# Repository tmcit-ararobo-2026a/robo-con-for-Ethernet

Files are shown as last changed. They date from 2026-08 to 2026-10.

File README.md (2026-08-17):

# <リポジトリ名>

<!-- 一行でプロジェクトを説明する -->
<プロジェクトの概要を1〜2文で記述>

## 目次

1. [概要](#1-概要)
2. [ドキュメント](#2-ドキュメント)
3. [コントリビューション](#3-コントリビューション)
4. [ビルド・使い方](#4-ビルド使い方)
5. [システム構成](#5-システム構成)
6. [ライセンス](#6-ライセンス)

## 1. 概要

<!-- プロジェクトの目的・背景・解決する課題を記述 -->

## 2. ドキュメント

| ドキュメント | 説明 |
| :-: | :-: |
| [CONTRIBUTING.md](./CONTRIBUTING.md) | 開発フロー・コミット規約・コーディング規約 |
| [docs/coding-rules.md](./docs/coding-rules.md) | コーディング規約の詳細 |
| [docs/uml/](./docs/uml/) | UML図 |

## 3. コントリビューション

[CONTRIBUTING.md](./CONTRIBUTING.md) を参照してください。

## 4. ビルド・使い方

<!-- ビルドのやり方 -->
<!-- 使い方 -->

## 5. システム構成

<!-- ROS2ノード構成・STM32との通信方式・ハードウェア構成 等 -->
<!-- 依存クラスが3つ以上ある場合は docs/uml/ にUML図を作成し、ここにリンクする -->

## 6. ライセンス

本リポジトリは [MITライセンス](./LICENSE) のもとで公開されています。

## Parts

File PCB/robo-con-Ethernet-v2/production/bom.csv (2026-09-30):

Designator | Footprint | Quantity | Value | LCSC Part #
C12, C13, C25, C38, C41, C42, C43, C44, C45, C46, C47, C48, C49, C50, C52, C53, C54, C55, C58, C59, C6 | 0402 | 21 | 0.1uF
C14, C15 | 0402 | 2 | 0.1u
C24, C56, C62, C63 | 0402 | 4 | 4.7uF
C26 | 0402 | 1 | 0.33uF
C28 | 0603 | 1 | 0.1uF
C29 | 0402 | 1 | 2.2uF
C34, C35 | 0402 | 2 | 18pF
C36, C37 | 0402 | 2 | 6.8nF
C39 | 0402 | 1 | 22nF
C40 | 0603 | 1 | 1nF
C51, C57, C60 | 0402 | 3 | 1uF
D1, D17 | 0603 | 2 | R
D10, D13, D5 | 0603 | 3 | B
D11, D12 | 0603 | 2 | W
D14, D15 | 0603 | 2 | O
D16, D3 | 0603 | 2 | G
F1 | 0603 | 1 | box
FB1 | 0603 | 1 | 600Ω/500mA
J1, J3 | JST_ZH_B5B-ZR_1x05_P1.50mm_Vertical | 2 | Conn_01x05
J2 | PinSocket_1x04_P2.54mm_Horizontal | 1 | Conn_01x04
J4 | RJ45_Bel_SI-60062-F | 1 | RJ45_Bel_SI-60062-F
J5 | JST_PH_S2B-PH-K_1x02_P2.00mm_Horizontal | 1 | Conn_01x02
R1, R7 | 0603 | 2 | 1k
R10, R22 | 0603 | 2 | 470
R11, R12, R13, R14, R2, R21, R25, R32, R33, R34, R35, R36, R4, R6, R79, R8, R9 | 0402 | 17 | 1k
R16 | 0402 | 1 | 10
R17, R18, R19, R20 | 0402 | 4 | 49.9k
R23 | 0603 | 1 | 10k
R24 | 0603 | 1 | 4k
R3 | 0402 | 1 | 12.3k
R53 | 0402 | 1 | 1M
R77, R78 | 0402 | 2 | 4.7k
SW1, SW2 | switch_TVAF06-A020B-R | 2 | SW_Push
SW3, SW4 | SKHHLPA010 | 2 | SW_Push
SW5 | 4MS1R202M6QES | 1 | SW_Push_SPDT
SW6, SW7 | 8MS8P1B05VS2QES-C13 | 2 | SW_Push_SPDT
U1 | LQFP-64_10x10mm_P0.5mm | 1 | STM32G474RCTx
U10 | SOT-23-5 | 1 | MCP73831-2-OT
U11, U15 | SOT-363_SC-70-6 | 2 | LM66100DCK
U18 | USB_C_Receptacle_Nelton_5077CR-16-SMC2-BK-TR | 1 | USB_Type-C
U3 | LQFP-48_7x7mm_P0.5mm | 1 | W5500
U5, U7 | RKJXV122400R | 2 | RKJXV122400R
U6 | SOT-89-5 | 1 | NJM2884U1-33
Y2 | XRCGB25M000FFS1AR0 | 1 | XRCGB25M000FFS1AR0

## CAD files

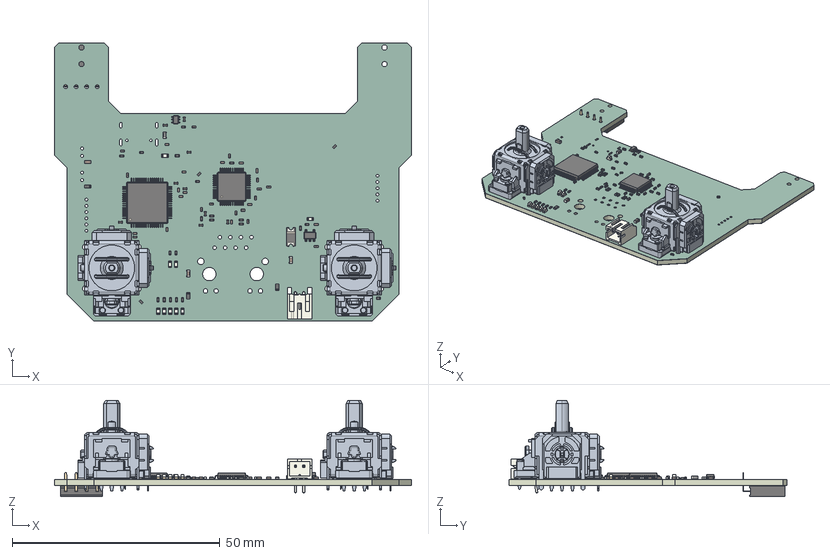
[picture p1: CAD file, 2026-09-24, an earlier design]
PCB/robo-con-Ethernet/.step
86.0 x 67.0 x 23.2 mm
C_0402_1005Metric x 35
R_0402_1005Metric x 26
R_0603_1608Metric x 3
LED_0603_1608Metric x 9
LQFP-64_10x10mm_P0.5mm
.step 1.34 x 2
JST_PH_S2B-PH-K_1x02_P2.00mm_Horizontal
D_2010_5025Metric
C_0603_1608Metric x 3
SOT-23-5
LQFP-48_7x7mm_P0.5mm
SOT-363_SC-70-6
L_0603_1608Metric
PinSocket_1x04_P2.54mm_Horizontal
robo-con-Ethernet_soldermask x 2
robo-con-Ethernet_PCB

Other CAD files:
PCB/robo-con-Ethernet/ほぼ使うやつ.step

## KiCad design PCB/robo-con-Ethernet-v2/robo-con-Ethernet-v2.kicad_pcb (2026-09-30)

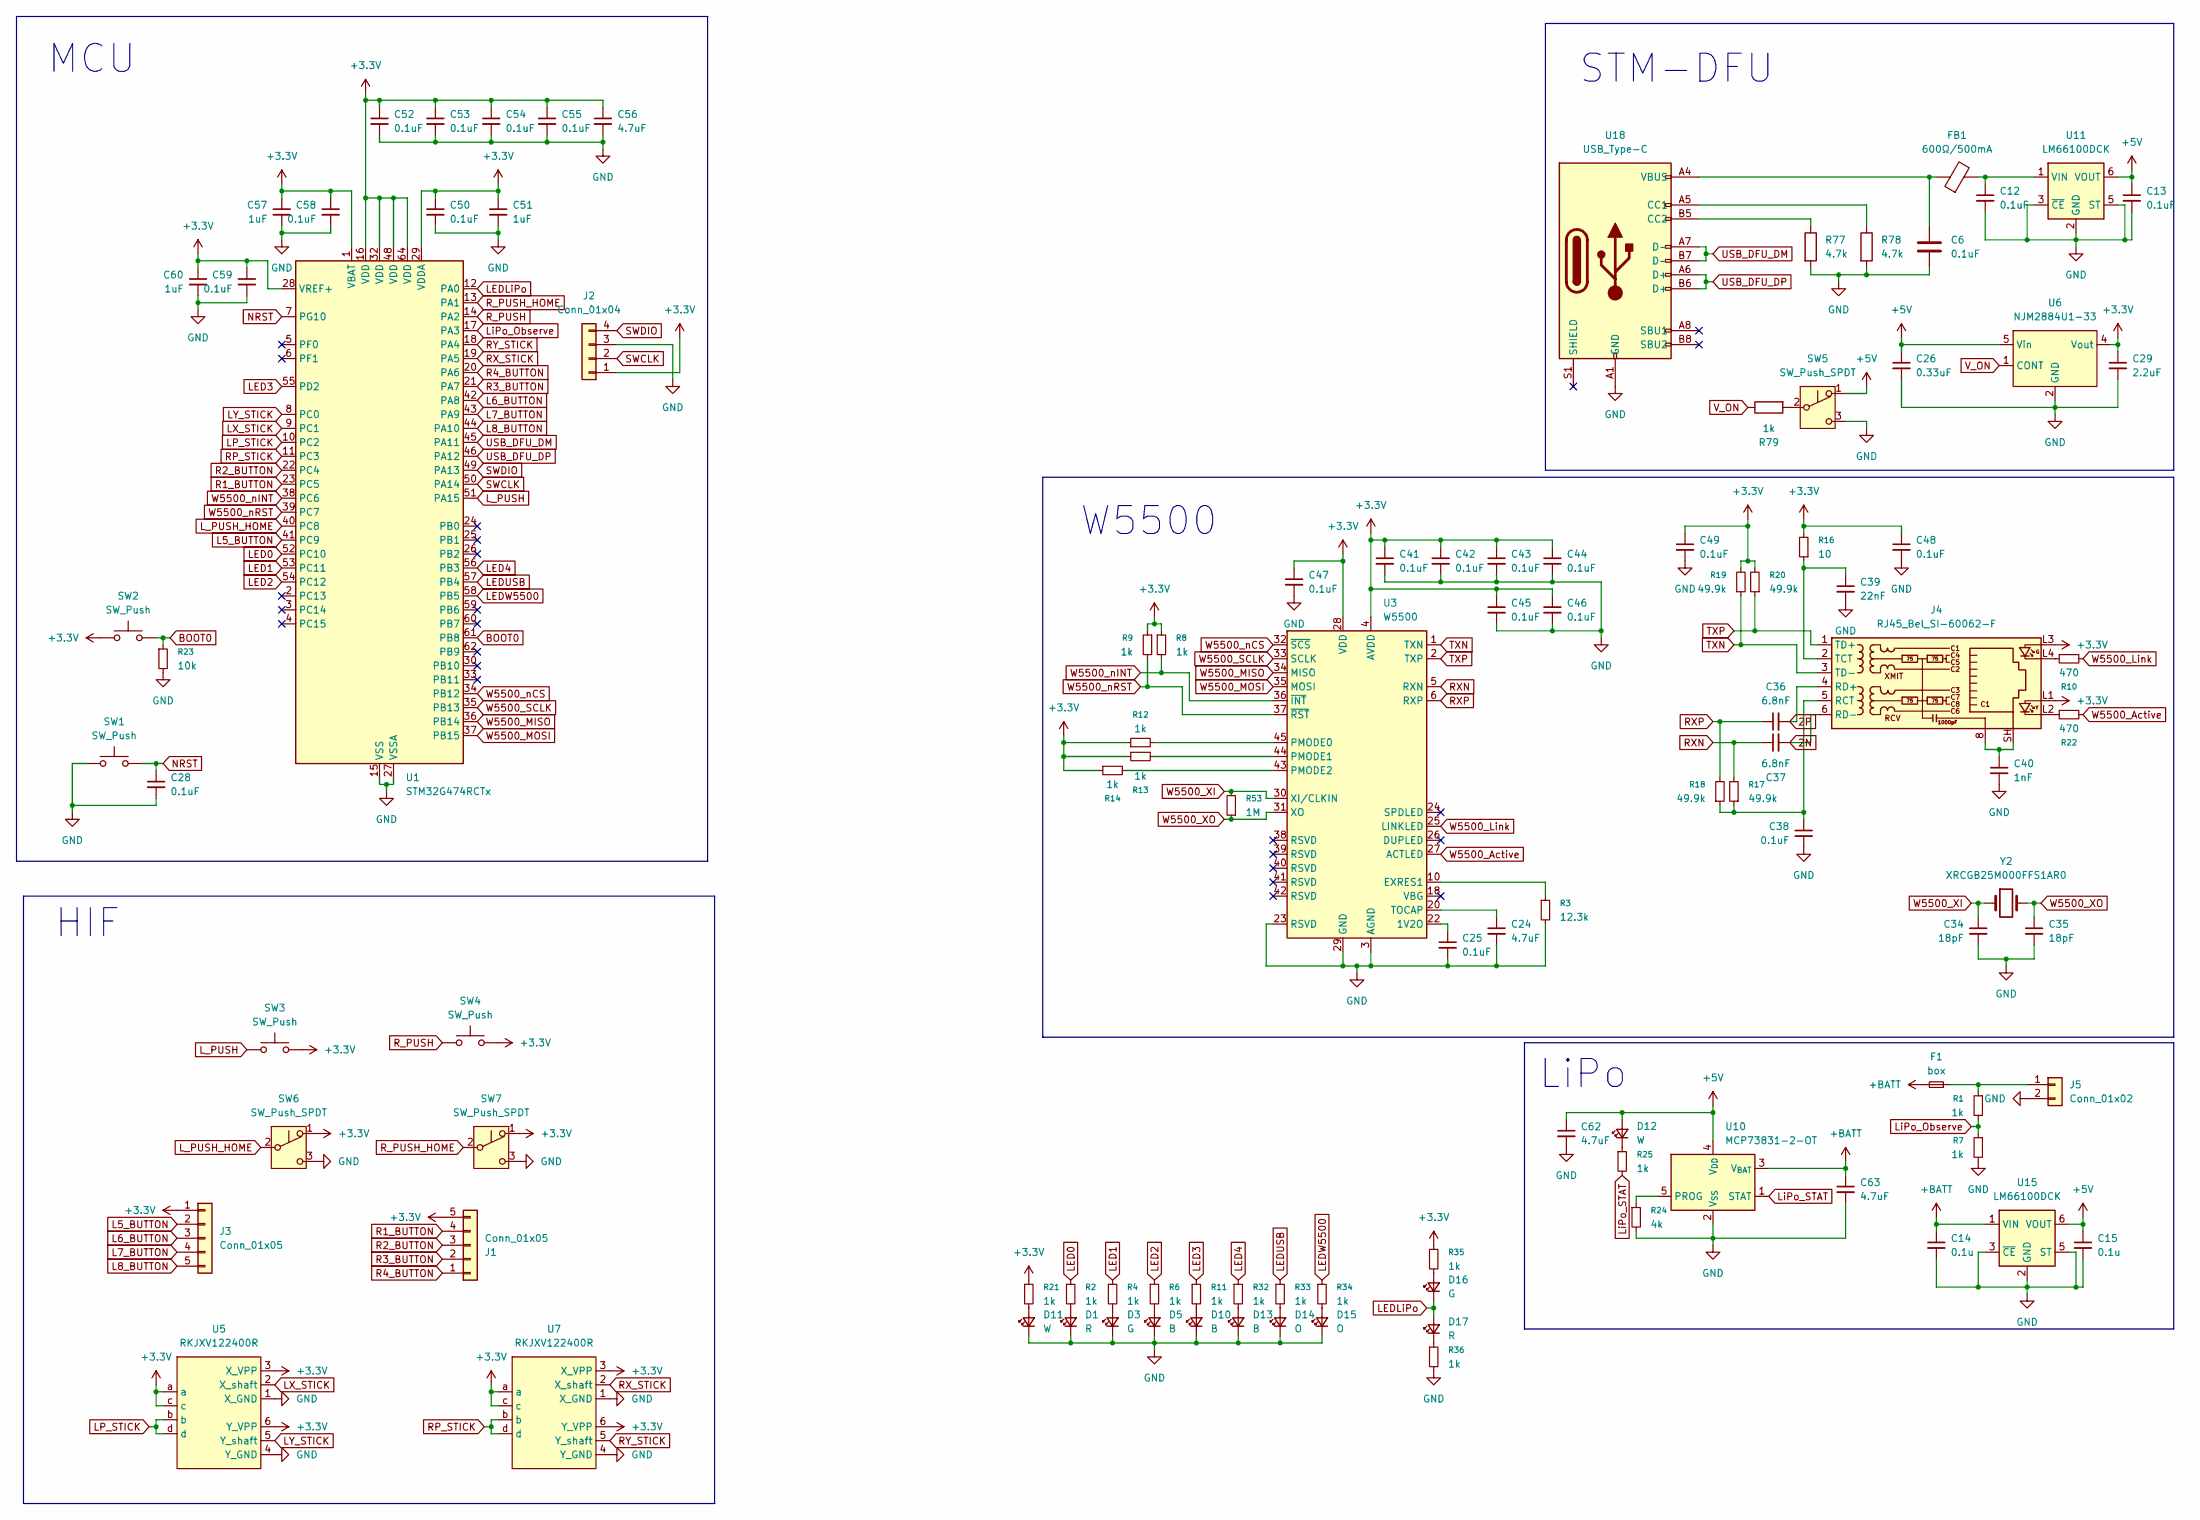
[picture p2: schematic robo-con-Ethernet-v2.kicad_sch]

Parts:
C6, C12, C13, C25, C38, C41, C42, C43, C44, C45, C46, C47, C48, C49, C50, C52, C53, C54, C55, C58, C59: 0.1uF; C_0402_1005Metric_Pad0.74x0.62mm_HandSolder
C14, C15: 0.1u; C_0402_1005Metric_Pad0.74x0.62mm_HandSolder
C24, C56, C62, C63: 4.7uF; C_0402_1005Metric_Pad0.74x0.62mm_HandSolder
C26: 0.33uF; C_0402_1005Metric_Pad0.74x0.62mm_HandSolder
C28: 0.1uF; C_0603_1608Metric_Pad1.08x0.95mm_HandSolder
C29: 2.2uF; C_0402_1005Metric_Pad0.74x0.62mm_HandSolder
C34, C35: 18pF; C_0402_1005Metric_Pad0.74x0.62mm_HandSolder
C36, C37: 6.8nF; C_0402_1005Metric_Pad0.74x0.62mm_HandSolder
C39: 22nF; C_0402_1005Metric_Pad0.74x0.62mm_HandSolder
C40: 1nF; C_0603_1608Metric_Pad1.08x0.95mm_HandSolder
C51, C57, C60: 1uF; C_0402_1005Metric_Pad0.74x0.62mm_HandSolder
D1, D17: R; LED_0603_1608Metric_Pad1.05x0.95mm_HandSolder
D3, D16: G; LED_0603_1608Metric_Pad1.05x0.95mm_HandSolder
D5, D10, D13: B; LED_0603_1608Metric_Pad1.05x0.95mm_HandSolder
D11, D12: W; LED_0603_1608Metric_Pad1.05x0.95mm_HandSolder
D14, D15: O; LED_0603_1608Metric_Pad1.05x0.95mm_HandSolder
F1: box; C_0603_1608Metric_Pad1.08x0.95mm_HandSolder
FB1: 600Ω/500mA; L_0603_1608Metric_Pad1.05x0.95mm_HandSolder
J1, J3: Conn_01x05; JST_ZH_B5B-ZR_1x05_P1.50mm_Vertical
J2: Conn_01x04; PinSocket_1x04_P2.54mm_Horizontal
J4: RJ45_Bel_SI-60062-F
J5: Conn_01x02; JST_PH_S2B-PH-K_1x02_P2.00mm_Horizontal
R1, R7: 1k; R_0603_1608Metric_Pad0.98x0.95mm_HandSolder
R2, R4, R6, R8, R9, R11, R12, R13, R14, R21, R25, R32, R33, R34, R35, R36, R79: 1k; R_0402_1005Metric_Pad0.72x0.64mm_HandSolder
R3: 12.3k; R_0402_1005Metric_Pad0.72x0.64mm_HandSolder
R10, R22: 470; R_0603_1608Metric_Pad0.98x0.95mm_HandSolder
R16: 10; R_0402_1005Metric_Pad0.72x0.64mm_HandSolder
R17, R18, R19, R20: 49.9k; R_0402_1005Metric_Pad0.72x0.64mm_HandSolder
R23: 10k; R_0603_1608Metric_Pad0.98x0.95mm_HandSolder
R24: 4k; R_0603_1608Metric_Pad0.98x0.95mm_HandSolder
R53: 1M; R_0402_1005Metric_Pad0.72x0.64mm_HandSolder
R77, R78: 4.7k; R_0402_1005Metric_Pad0.72x0.64mm_HandSolder
SW1, SW2: SW_Push; switch_TVAF06-A020B-R
SW3, SW4: SW_Push; SKHHLPA010
SW5: SW_Push_SPDT; 4MS1R202M6QES
SW6, SW7: SW_Push_SPDT; 8MS8P1B05VS2QES-C13
U1: STM32G474RCTx; LQFP-64_10x10mm_P0.5mm
U3: W5500; LQFP-48_7x7mm_P0.5mm
U5, U7: RKJXV122400R
U6: NJM2884U1-33; SOT-89-5
U10: MCP73831-2-OT; SOT-23-5
U11, U15: LM66100DCK; SOT-363_SC-70-6
U18: USB_Type-C; USB_C_Receptacle_Nelton_5077CR-16-SMC2-BK-TR
Y2: XRCGB25M000FFS1AR0

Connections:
2N: C37.2, J4.6 (RD-)
2P: C36.2, J4.4 (RD+)
+3.3V: C29.1, C41.1, C42.1, C43.1, C44.1, C45.1, C46.1, C47.1, C48.1, C49.1, C50.1, C51.1, C52.1, C53.1, C54.1, C55.1, C56.1, C57.1, C58.1, C59.1, C60.1, J1.5, J2.1, J3.1, J4.L1, J4.L3, R8.1, R9.1, R12.1, R13.1, R14.1, R16.2, R19.2, R20.2, R21.1, R35.1, SW2.1, SW3.2, SW4.2, SW6.1 (A), SW7.1 (A), U1.1 (VBAT), U1.16 (VDD), U1.28 (VREF+), U1.29 (VDDA), U1.32 (VDD), U1.48 (VDD), U1.64 (VDD), U3.4 (AVDD), U3.8 (AVDD), U3.11 (AVDD), U3.15 (AVDD), U3.17 (AVDD), U3.21 (AVDD), U3.28 (VDD), U5.3 (X_VPP), U5.6 (Y_VPP), U5.a, U5.c, U6.4 (Vout), U7.3 (X_VPP), U7.6 (Y_VPP), U7.a, U7.c
+5V: C13.1, C15.1, C26.1, C62.1, D12.2 (A), SW5.1 (A), U6.5 (Vin), U10.4 (V_{DD}), U11.6 (VOUT), U15.6 (VOUT)
+BATT: C14.1, C63.1, F1.2, U10.3 (V_{BAT}), U15.1 (VIN)
BOOT0: R23.1, SW2.2, U1.61 (PB8)
GND: C6.2, C12.2, C13.2, C14.2, C15.2, C24.2, C25.2, C26.2, C28.2, C29.2, C34.2, C35.2, C38.2, C39.2, C40.2, C41.2, C42.2, C43.2, C44.2, C45.2, C46.2, C47.2, C48.2, C49.2, C50.2, C51.2, C52.2, C53.2, C54.2, C55.2, C56.2, C57.2, C58.2, C59.2, C60.2, C62.2, C63.2, D1.1 (K), D3.1 (K), D5.1 (K), D10.1 (K), D11.1 (K), D13.1 (K), D14.1 (K), D15.1 (K), J2.3, J5.2, R3.2, R7.2, R23.2, R24.2, R36.2, R77.2, R78.2, SW1.1, SW5.3 (C), SW6.3 (C), SW7.3 (C), U1.15 (VSS), U1.27 (VSSA), U1.31 (VSS), U1.47 (VSS), U1.63 (VSS), U3.3 (AGND), U3.9 (AGND), U3.14 (AGND), U3.16 (AGND), U3.19 (AGND), U3.23 (RSVD), U3.29 (GND), U3.48 (AGND), U5.1 (X_GND), U5.4 (Y_GND), U6.2 (GND), U7.1 (X_GND), U7.4 (Y_GND), U10.2 (V_{SS}), U11.2 (GND), U11.3 (~CE), U11.5 (ST), U15.2 (GND), U15.3 (~CE), U15.5 (ST), U18.A1 (GND), U18.B1 (GND)
L5_BUTTON: J3.2, U1.41 (PC9)
L6_BUTTON: J3.3, U1.42 (PA8)
L7_BUTTON: J3.4, U1.43 (PA9)
L8_BUTTON: J3.5, U1.44 (PA10)
LED0: R2.1, U1.52 (PC10)
LED1: R4.1, U1.53 (PC11)
LED2: R6.1, U1.54 (PC12)
LED3: R11.1, U1.55 (PD2)
LED4: R32.1, U1.56 (PB3)
LEDLiPo: D16.1 (K), D17.2 (A), U1.12 (PA0)
LEDUSB: R33.1, U1.57 (PB4)
LEDW5500: R34.1, U1.58 (PB5)
LP_STICK: U1.10 (PC2), U5.b, U5.d
LX_STICK: U1.9 (PC1), U5.2 (X_shaft)
LY_STICK: U1.8 (PC0), U5.5 (Y_shaft)
L_PUSH: SW3.1, U1.51 (PA15)
L_PUSH_HOME: SW6.2 (B), U1.40 (PC8)
LiPo_Observe: R1.2, R7.1, U1.17 (PA3)
LiPo_STAT: R25.2, U10.1 (STAT)
NRST: C28.1, SW1.2, U1.7 (PG10)
unnamed: C6.1, FB1.1, U18.A4 (VBUS), U18.B4 (VBUS)
unnamed: C40.1, J4.8, J4.SH
unnamed: D1.2 (A), R2.2
unnamed: D3.2 (A), R4.2
unnamed: D5.2 (A), R6.2
unnamed: D10.2 (A), R11.2
unnamed: D11.2 (A), R21.2
unnamed: D12.1 (K), R25.1
unnamed: D13.2 (A), R32.2
unnamed: D14.2 (A), R33.2
unnamed: D15.2 (A), R34.2
unnamed: D16.2 (A), R35.2
unnamed: D17.1 (K), R36.1
unnamed: J4.L2, R22.1
unnamed: J4.L4, R10.1
unnamed: C38.1, J4.5 (RCT), R17.1, R18.1
unnamed: C39.1, J4.2 (TCT), R16.1
unnamed: F1.1, J5.1, R1.1
unnamed: R79.2, SW5.2 (B)
unnamed: C25.1, U3.22 (1V2O)
unnamed: R3.1, U3.10 (EXRES1)
unnamed: R12.2, U3.45 (PMODE0)
unnamed: R13.2, U3.44 (PMODE1)
unnamed: R14.2, U3.43 (PMODE2)
unnamed: C24.1, U3.20 (TOCAP)
unnamed: R24.1, U10.5 (PROG)
unnamed: C12.1, FB1.2, U11.1 (VIN)
unnamed: R78.1, U18.A5 (CC1)
unnamed: R77.1, U18.B5 (CC2)
R1_BUTTON: J1.4, U1.23 (PC5)
R2_BUTTON: J1.3, U1.22 (PC4)
R3_BUTTON: J1.2, U1.21 (PA7)
R4_BUTTON: J1.1, U1.20 (PA6)
RP_STICK: U1.11 (PC3), U7.b, U7.d
RXN: C37.1, R17.2, U3.5 (RXN)
RXP: C36.1, R18.2, U3.6 (RXP)
RX_STICK: U1.19 (PA5), U7.2 (X_shaft)
RY_STICK: U1.18 (PA4), U7.5 (Y_shaft)
R_PUSH: SW4.1, U1.14 (PA2)
R_PUSH_HOME: SW7.2 (B), U1.13 (PA1)
SWCLK: J2.2, U1.50 (PA14)
SWDIO: J2.4, U1.49 (PA13)
TXN: J4.3 (TD-), R19.1, U3.1 (TXN)
TXP: J4.1 (TD+), R20.1, U3.2 (TXP)
USB_DFU_DM: U1.45 (PA11), U18.A7 (D-), U18.B7 (D-)
USB_DFU_DP: U1.46 (PA12), U18.A6 (D+), U18.B6 (D+)
V_ON: R79.1, U6.1 (CONT)
W5500_Active: R22.2, U3.27 (ACTLED)
W5500_Link: R10.2, U3.25 (LINKLED)
W5500_MISO: U1.36 (PB14), U3.34 (MISO)
W5500_MOSI: U1.37 (PB15), U3.35 (MOSI)
W5500_SCLK: U1.35 (PB13), U3.33 (SCLK)
W5500_XI: C34.1, R53.2, U3.30 (XI/CLKIN), Y2.1
W5500_XO: C35.1, R53.1, U3.31 (XO), Y2.3 (2)
W5500_nCS: U1.34 (PB12), U3.32 (~SCS)
W5500_nINT: R8.2, U1.38 (PC6), U3.36 (~INT)
W5500_nRST: R9.2, U1.39 (PC7), U3.37 (~RST)

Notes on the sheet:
LiPo
W5500
STM-DFU
MCU
HIF

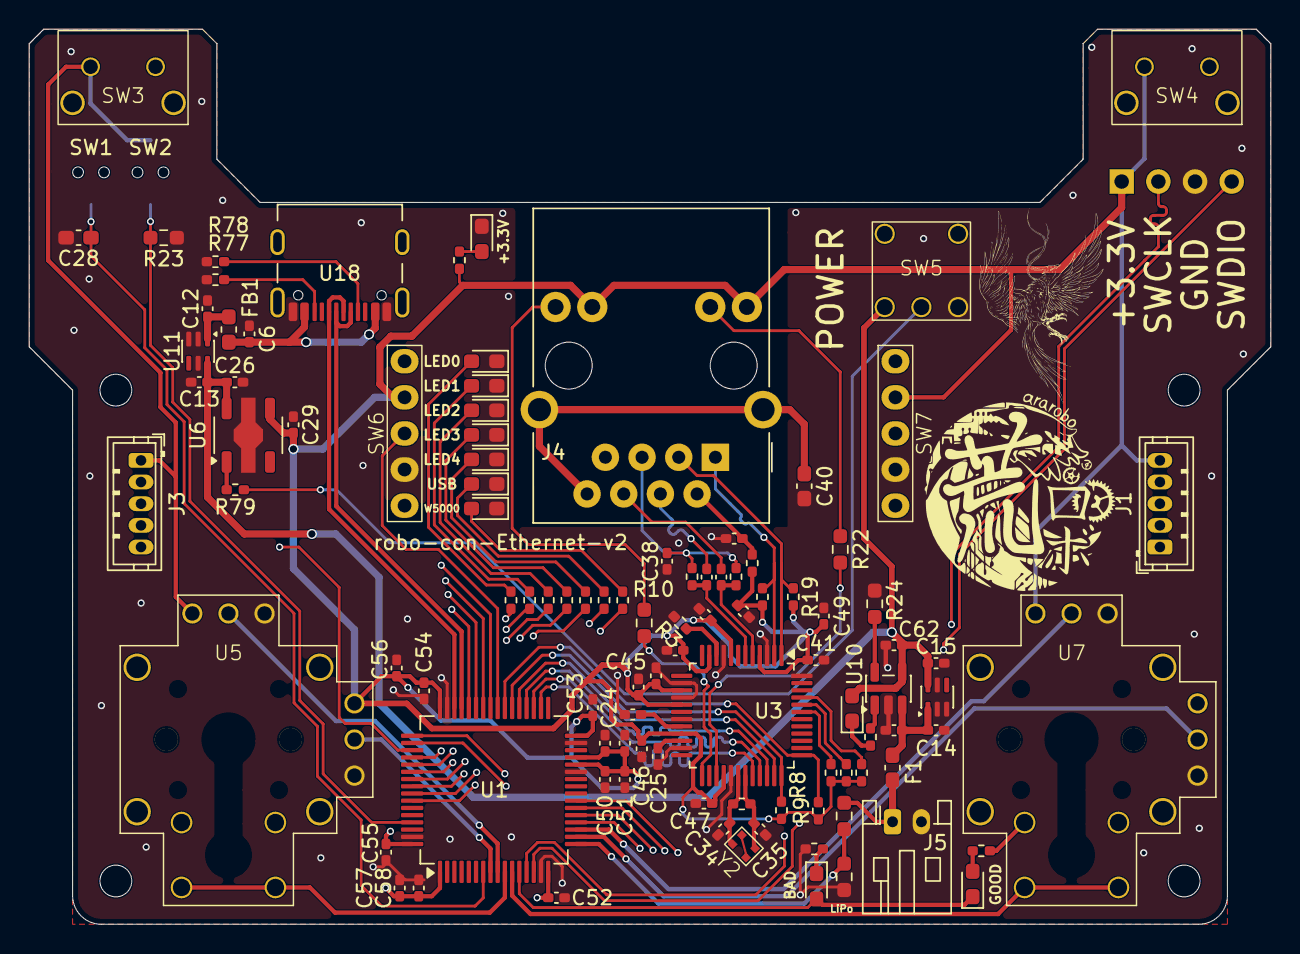
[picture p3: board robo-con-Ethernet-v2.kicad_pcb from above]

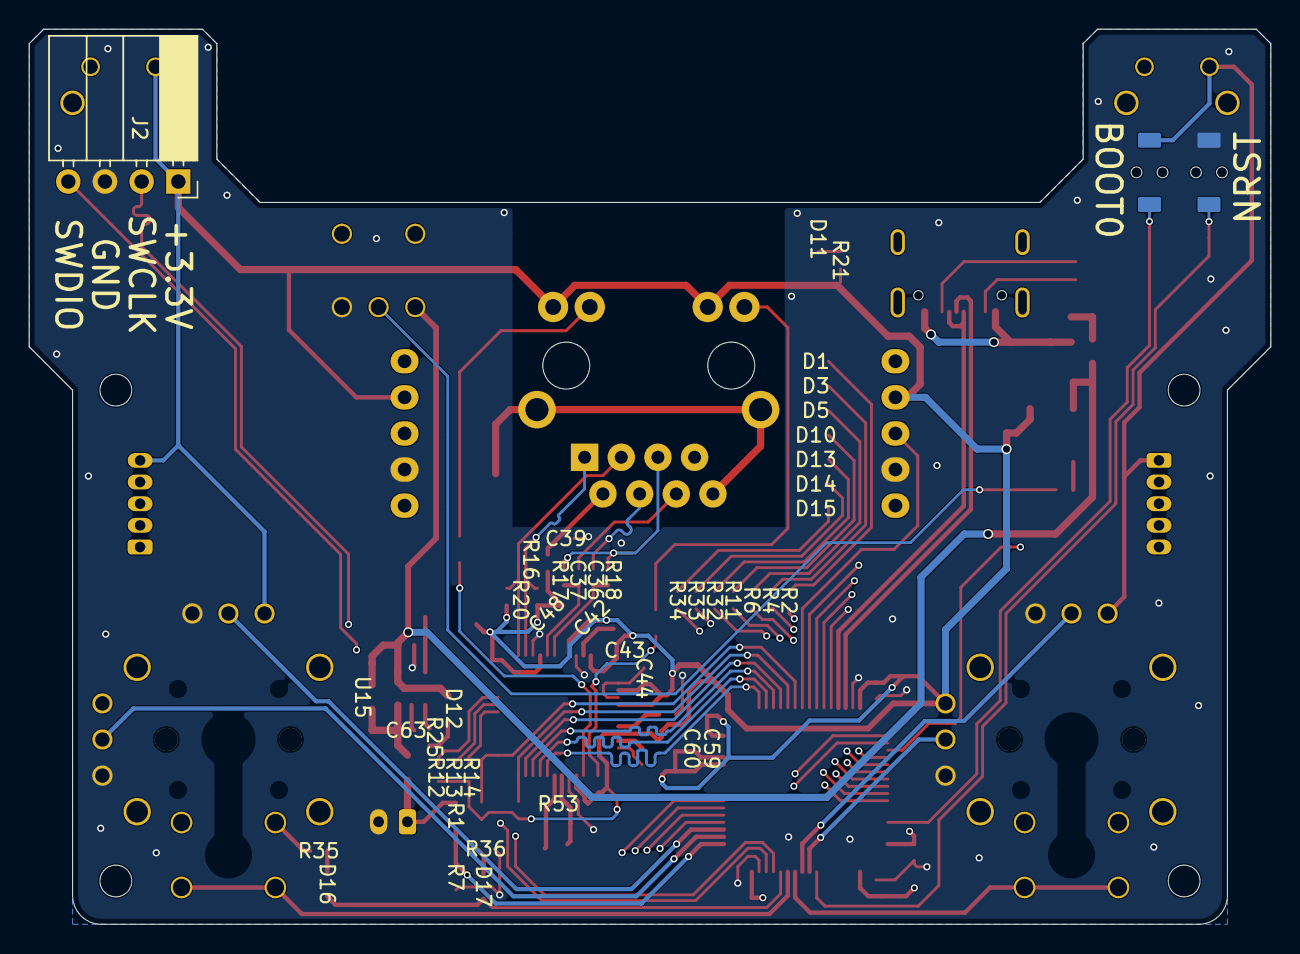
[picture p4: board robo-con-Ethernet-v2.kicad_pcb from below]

Board: 4 copper layers, 86.0 x 62.0 mm, 106 parts (3 on the bottom side), 84 nets.

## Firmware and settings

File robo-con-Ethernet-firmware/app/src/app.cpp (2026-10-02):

#include "app/app.hpp"

#include <algorithm>
#include <cstdint>
#include <cstdio>

#include "adc.h"
#include "app/robot_config.hpp"
#include "app/robot_ethernet.hpp"
#include "app/stick_config.hpp"
#include "tim.h"

namespace {

bool timer_triggered = false;
robot_config::teleop_t teleop;
RobotEthernet ether;
uint16_t adc_raw_value[4];
void mcu_wake_led()
{
    HAL_GPIO_WritePin(LED0_GPIO_Port, LED0_Pin, GPIO_PIN_SET);
    HAL_Delay(100);
    HAL_GPIO_WritePin(LED1_GPIO_Port, LED1_Pin, GPIO_PIN_SET);
    HAL_Delay(100);
    HAL_GPIO_WritePin(LED2_GPIO_Port, LED2_Pin, GPIO_PIN_SET);
    HAL_Delay(100);
    HAL_GPIO_WritePin(LED3_GPIO_Port, LED3_Pin, GPIO_PIN_SET);
    HAL_Delay(100);
    HAL_GPIO_WritePin(LED4_GPIO_Port, LED4_Pin, GPIO_PIN_SET);
    HAL_Delay(100);
    HAL_GPIO_WritePin(LED_USB_GPIO_Port, LED_USB_Pin, GPIO_PIN_SET);
    HAL_Delay(100);
    HAL_GPIO_WritePin(LED_W5500_GPIO_Port, LED_W5500_Pin, GPIO_PIN_SET);
    HAL_Delay(100);

    HAL_GPIO_WritePin(LED0_GPIO_Port, LED0_Pin, GPIO_PIN_RESET);
    HAL_Delay(100);
    HAL_GPIO_WritePin(LED1_GPIO_Port, LED1_Pin, GPIO_PIN_RESET);
    HAL_Delay(100);
    HAL_GPIO_WritePin(LED2_GPIO_Port, LED2_Pin, GPIO_PIN_RESET);
    HAL_Delay(100);
    HAL_GPIO_WritePin(LED3_GPIO_Port, LED3_Pin, GPIO_PIN_RESET);
    HAL_Delay(100);
    HAL_GPIO_WritePin(LED4_GPIO_Port, LED4_Pin, GPIO_PIN_RESET);
    HAL_Delay(100);
    HAL_GPIO_WritePin(LED_USB_GPIO_Port, LED_USB_Pin, GPIO_PIN_RESET);
    HAL_Delay(100);
    HAL_GPIO_WritePin(LED_W5500_GPIO_Port, LED_W5500_Pin, GPIO_PIN_RESET);
}
/* Hartbeat LED用 */
constexpr uint32_t k_heartbeat_toggle_interval_ms = 500;
uint32_t heartbeat_last_toggle_time_ms            = 0;
/**
 * @brief 一定周期のLEDチカチカ処理
 *
 */
void update_heartbeat_led()
{
    const uint32_t now_ms = HAL_GetTick();
    if ((now_ms - heartbeat_last_toggle_time_ms) >= k_heartbeat_toggle_interval_ms) {
        heartbeat_last_toggle_time_ms = now_ms;
        HAL_GPIO_TogglePin(LED4_GPIO_Port, LED4_Pin);
    }
}
/* TelopRate */
constexpr uint32_t k_teleop_count_max = 10 / 2;
uint32_t teleop_count                 = 0;
/**
 * @brief 10回に1回LEDをトグルする
 *
 */
void update_teleop_rate_led()
{
    teleop_count++;
    if (teleop_count >= k_teleop_count_max) {
        teleop_count = 0;
        HAL_GPIO_TogglePin(LED3_GPIO_Port, LED3_Pin);
    }
}
/**
 * @brief uint16のADC後の値をint8へ正規化（デッドゾーン処理付き）
 *
 * @param target_adc_buffer 処理するADC値
 * @param zero_reference ADCのセンター（中立）値
 * @param min センターからの負方向の最大偏差（負の整数、例: -115）
 * @param max センターからの正方向の最大偏差（正の整数、例: 115）
 */
int8_t normalize_adc_value(uint16_t target_adc_buffer, int zero_reference, int min, int max)
{
    // センター位置からの偏差を計算
    int diff = static_cast<int>(target_adc_buffer) - zero_reference;

    // デッドゾーン（±10）の範囲内なら 0 を返す
    if (std::abs(diff) <= STICK_CENTER_MARGIN) {
        return 0;
    }

    int scaled_value = 0;

    if (diff > STICK_CENTER_MARGIN) {
        // 正の方向: デッドゾーンを超えた分を 0 ~ STICK_REFERENCE_MAX にスケーリング
        const int effective_range = max - STICK_CENTER_MARGIN;
        if (effective_range > 0) {
            scaled_value = (diff - STICK_CENTER_MARGIN) * STICK_REFERENCE_MAX / effective_range;
        }
    } else {
        // 負の方向: デッドゾーンを超えた分を 0 ~ -STICK_REFERENCE_MAX にスケーリング
        const int effective_range = std::abs(min) - STICK_CENTER_MARGIN;  // -min で絶対値化
        if (effective_range > 0) {
            scaled_value = (diff + STICK_CENTER_MARGIN) * STICK_REFERENCE_MAX / effective_range;
        }
    }
    return static_cast<int8_t>(std::clamp(scaled_value, -STICK_REFERENCE_MAX, STICK_REFERENCE_MAX));
}

void update_stick_values()
{
    teleop.analog.stick_right[0] =
        -normalize_adc_value(adc_raw_value[3], STICK_X_R_CENTER, STICK_X_R_MIN, STICK_X_R_MAX);
    teleop.analog.stick_right[1] =
        normalize_adc_value(adc_raw_value[2], STICK_Y_R_CENTER, STICK_Y_R_MIN, STICK_Y_R_MAX);
    teleop.analog.stick_left[0] =
        -normalize_adc_value(adc_raw_value[0], STICK_X_L_CENTER, STICK_X_L_MIN, STICK_X_L_MAX);
    teleop.analog.stick_left[1] =
        normalize_adc_value(adc_raw_value[1], STICK_Y_L_CENTER, STICK_Y_L_MIN, STICK_Y_L_MAX);
}

void update_buttons_value()
{
    teleop.buttons.left_up          = HAL_GPIO_ReadPin(BUTTON_L1_GPIO_Port, BUTTON_L1_Pin);
    teleop.buttons.left_down        = HAL_GPIO_ReadPin(BUTTON_L2_GPIO_Port, BUTTON_L2_Pin);
    teleop.buttons.left_right       = HAL_GPIO_ReadPin(BUTTON_L3_GPIO_Port, BUTTON_L3_Pin);
    teleop.buttons.left_left        = HAL_GPIO_ReadPin(BUTTON_L4_GPIO_Port, BUTTON_L4_Pin);
    teleop.buttons.right_right      = HAL_GPIO_ReadPin(BUTTON_R5_GPIO_Port, BUTTON_R5_Pin);
    teleop.buttons.right_up         = HAL_GPIO_ReadPin(BUTTON_R6_GPIO_Port, BUTTON_R6_Pin);
    teleop.buttons.right_down       = HAL_GPIO_ReadPin(BUTTON_R7_GPIO_Port, BUTTON_R7_Pin);
    teleop.buttons.stick_push_left  = HAL_GPIO_ReadPin(STICK_PUSH_L_GPIO_Port, STICK_PUSH_L_Pin);
    teleop.buttons.stick_push_right = HAL_GPIO_ReadPin(STICK_PUSH_R_GPIO_Port, STICK_PUSH_R_Pin);
}

void send_teleop()
{
    // teleopの値を更新
    update_stick_values();
    update_buttons_value();
    // Ethernetで送信
    ether.send_teleop(teleop);
    // デバッグ表示
    /*
    printf(
        "teleop: stick_r=(%d,%d) stick_l=(%d,%d), buttons: right: %d, %d, %d, left: %d, %d, %d,
    %d\n", teleop.analog.stick_right[0], teleop.analog.stick_right[1], teleop.analog.stick_left[0],
        teleop.analog.stick_left[1],
        teleop.buttons.right_up,
        teleop.buttons.right_down,
        teleop.buttons.right_right,
        teleop.buttons.left_up,
        teleop.buttons.left_down,
        teleop.buttons.left_right,
        teleop.buttons.left_left
    );
    */
    update_teleop_rate_led();
}
}  // namespace

void setup()
{
    mcu_wake_led();
    if (HAL_ADC_Start_DMA(&hadc1, (uint32_t*)adc_raw_value, 4) != HAL_OK) {
        Error_Handler();
    }
    if (ether.init()) {
        HAL_GPIO_WritePin(LED_W5500_GPIO_Port, LED_W5500_Pin, GPIO_PIN_SET);
    }
    HAL_TIM_Base_Start_IT(&htim6);
    heartbeat_last_toggle_time_ms = HAL_GetTick();
    HAL_GPIO_WritePin(LED1_GPIO_Port, LED1_Pin, GPIO_PIN_SET);
}

void loop()
{
    if (timer_triggered) {
        send_teleop();
        timer_triggered = false;
    }
    update_heartbeat_led();
}
extern "C" {

void HAL_TIM_PeriodElapsedCallback(TIM_HandleTypeDef* htim)
{
    if (htim->Instance == htim6.Instance) {  // 100Hz timer
        timer_triggered = true;
    }
}
}

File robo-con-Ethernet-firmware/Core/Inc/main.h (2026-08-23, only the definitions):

#define LED4_Pin GPIO_PIN_13
#define LED4_GPIO_Port GPIOC
#define LED3_Pin GPIO_PIN_14
#define LED3_GPIO_Port GPIOC
#define LED2_Pin GPIO_PIN_15
#define LED2_GPIO_Port GPIOC
#define LED1_Pin GPIO_PIN_0
#define LED1_GPIO_Port GPIOF
#define LED0_Pin GPIO_PIN_1
#define LED0_GPIO_Port GPIOF
#define STICK_X_L_Pin GPIO_PIN_0
#define STICK_X_L_GPIO_Port GPIOC
#define STICK_Y_L_Pin GPIO_PIN_1
#define STICK_Y_L_GPIO_Port GPIOC
#define STICK_PUSH_L_Pin GPIO_PIN_2
#define STICK_PUSH_L_GPIO_Port GPIOC
#define STICK_PUSH_R_Pin GPIO_PIN_3
#define STICK_PUSH_R_GPIO_Port GPIOC
#define SPI1_CS_Pin GPIO_PIN_4
#define SPI1_CS_GPIO_Port GPIOA
#define W5500_IT_Pin GPIO_PIN_0
#define W5500_IT_GPIO_Port GPIOB
#define W5500_RST_Pin GPIO_PIN_1
#define W5500_RST_GPIO_Port GPIOB
#define STICK_X_R_Pin GPIO_PIN_11
#define STICK_X_R_GPIO_Port GPIOB
#define STICK_Y_R_Pin GPIO_PIN_12
#define STICK_Y_R_GPIO_Port GPIOB
#define BUTTON_R5_Pin GPIO_PIN_13
#define BUTTON_R5_GPIO_Port GPIOB
#define BUTTON_R6_Pin GPIO_PIN_14
#define BUTTON_R6_GPIO_Port GPIOB
#define BUTTON_R7_Pin GPIO_PIN_15
#define BUTTON_R7_GPIO_Port GPIOB
#define LEVER_R2_Pin GPIO_PIN_6
#define LEVER_R2_GPIO_Port GPIOC
#define LEVER_R1_Pin GPIO_PIN_7
#define LEVER_R1_GPIO_Port GPIOC
#define LEVER_R0_Pin GPIO_PIN_8
#define LEVER_R0_GPIO_Port GPIOC
#define LEVER_R4_Pin GPIO_PIN_9
#define LEVER_R4_GPIO_Port GPIOC
#define LEVER_R3_Pin GPIO_PIN_8
#define LEVER_R3_GPIO_Port GPIOA
#define LED_W5500_Pin GPIO_PIN_9
#define LED_W5500_GPIO_Port GPIOA
#define LED_USB_Pin GPIO_PIN_10
#define LED_USB_GPIO_Port GPIOA
#define BUTTON_L1_Pin GPIO_PIN_15
#define BUTTON_L1_GPIO_Port GPIOA
#define BUTTON_L2_Pin GPIO_PIN_10
#define BUTTON_L2_GPIO_Port GPIOC
#define BUTTON_L3_Pin GPIO_PIN_11
#define BUTTON_L3_GPIO_Port GPIOC
#define BUTTON_L4_Pin GPIO_PIN_12
#define BUTTON_L4_GPIO_Port GPIOC
#define LEVER_L3_Pin GPIO_PIN_3
#define LEVER_L3_GPIO_Port GPIOB
#define LEVER_L4_Pin GPIO_PIN_4
#define LEVER_L4_GPIO_Port GPIOB
#define LEVER_L0_Pin GPIO_PIN_5
#define LEVER_L0_GPIO_Port GPIOB
#define LEVER_L2_Pin GPIO_PIN_6
#define LEVER_L2_GPIO_Port GPIOB
#define LEVER_L1_Pin GPIO_PIN_7
#define LEVER_L1_GPIO_Port GPIOB

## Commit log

2026-08-17 Ethernetコントローラーの作成
    [bom.csv, designators.csv, positions.csv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]
2026-08-17 ioc ファイルの作成
2026-08-19 feat:初期コード生成
2026-08-19 feat:C++用花形作成
2026-08-19 feat:GPIOピンの名前一致
2026-08-19 feat:通信用設定ファイルを追加
2026-08-19 feat:GPIOをALL CAPSにした
2026-08-21 feat:ジョイスティックの正規化関数を作成
2026-08-21 feat:ボタンの値を読む関数追加
2026-08-21 fix:}忘れ
2026-08-21 feat:仮想COM作成
2026-08-21 feat:printf実装
2026-08-21 feat:LRstick追加
2026-08-21 feat:書き込めるようにした
2026-08-21 chore:コントローラーのスティックのプラマイ反転した。
2026-08-22 feat:右レバーも同様に修正
2026-08-22 fix:括弧わすれ
2026-08-22 feat:RobotEthernet追加
2026-08-22 feat:Ethernetによる送信を追加
2026-08-22 feat:タイマーで100Hz動作
2026-08-22 fix:ビルドパス修正
2026-08-23 feat:timerが動かん
2026-08-23 fix:メモリ不正アクセス
2026-08-23 feat:LEDの色やシルクに合わせて修正
2026-08-23 feat:起動時のLED演出追加
2026-08-26 feat:不感帯適用WIP
2026-08-26 feat:不感帯適用を実装
2026-08-27 fix:不感帯適用時に絶対値になってしまうバグ
2026-09-02 feat:robot-config更新
2026-09-02 fix:robot-configに合わせて修正
2026-09-18 feat:1つ目のコントローラのキャリブレーション値
2026-09-24 LiPo監視 SWの追加 タクトスイッチ移した ...
    [robo-con-Ethernet-v2.kicad_pcb, robo-con-Ethernet-v2.kicad_sch]
2026-09-24 ioc と 基板やった
    [.step, robo-con-Ethernet-v2.kicad_pcb]
2026-09-28 update pcb
    [robo-con-Ethernet-v2.kicad_pcb, robo-con-Ethernet-v2.kicad_sch]
2026-09-28 PCBのGNDビア打ち以外終了 iocファイルとの照合はまだ 明日やる
    [robo-con-Ethernet-v2.kicad_pcb, robo-con-Ethernet-v2.kicad_sch]
2026-09-28 ioc 比較済み
    [robo-con-Ethernet-v2.kicad_pcb, robo-con-Ethernet-v2.kicad_sch]
2026-09-30 v2 PCB ガーバー
    [bom.csv, designators.csv, positions.csv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]
2026-10-02 feat:最新のrobot configファイルに変更
2026-10-07 feat:最新のrobot config
2026-10-15 feat:作り直し
2026-10-15 feat:v1からメインコードの引き継ぎ
2026-10-15 feat:core処理追加
2026-10-15 fix:buildが通るように修正
2026-10-15 feat:ボタン名をleverからtriggerに変更、v2の仕様に合わせてボタン追加

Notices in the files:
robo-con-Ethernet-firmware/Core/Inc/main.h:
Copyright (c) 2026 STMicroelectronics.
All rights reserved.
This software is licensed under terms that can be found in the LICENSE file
